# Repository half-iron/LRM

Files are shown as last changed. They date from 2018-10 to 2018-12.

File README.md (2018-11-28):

# LRM übersicht

### Ordner

- `axle_sensors` achsensoren info und firmware
- `NTiXL2` entält die python implementierung der serielle schnittstelle zur XL2 messgerät. Diesem Modul  
- `pyLRM` entält den python code notwendig für die scripts.

### Scripts

Die scripts dienen zur Bedienung der Messanlage. Die Scripts implementieren eine rehie von 
funktionen. Den Befehl `python3 scriptname.py -h` gibt Hinweise über die funktionalität und
 Anwendug der Scripts. 
 
Ein übersicht der implementierten funktionalitäten sind: 
- **xl2_device.py**: 
    - XL2 cycle power (strom aus und wieder ein)
    - XL2 test serial
    - XL2 mass <-> serial mode wechseln
    - XL2 mass mount und umount
    
- **messung.py** durchführt die Messung. Messdaten werden sowohl im XL2 wie im BBG generiert.

- **assign_tools.py**. Nach einer Messung müssen die XL2 und BBG Messdaten miteinander zugeordnet werden.

- **test_mail_logger.py** sendet einen testmail
    
- **test_axle_sensors.py** um axle sensor zu testen. ähnlich zur `messung.py` aber ohne XL2.

## Durchführung einer Messung
### Vorbereitungen

1. `pyLRM/config.py` file modifizieren falls nötig.

2. `pyLRM/passby.py` file modifizieren. Diesem File enthält die logik um die passby zu generieren. In zukunft diese änderung 
sollten in `pyLRM/config.py` durchgeführt werden durch subclassen von `passby.Passby` und neuschreiben der methode `run`

3. `pyLRM`, `NTiXL2`, Scripts und secret file auf BBG hochladen. 

### Messen

1. Stelle sicher dass den XL2 korrekt funktioniert und im serial modus ist. Benutze dafür 
den `xl2_device.py` script. z.B. mit:
    ```
    python3 xl2_device.py -test_serial
    ```
2. Starte die Messung mit  

    ```
       python3 messung.py TestMessung
    ```
    
    Den ordner `~\TestMessung` wird erstellt. Messdaten und logs sind dorthin gespeichert.
      
    Damit die messung auch nach den ssh logout weiterläuft muss den befehl in einen [screen](https://linuxize.com/post/how-to-use-linux-screen/) 
    Session  durchgeführt werden.
      
    ```bash
       screen
    ```
    Um den screen Session zu verlassen ctr-a d (detach).  
    Um den screen Session wieder zu öffnen `screen -r`
    Um den screen Session zu schliessen ctr-a k (kill).  

3. Stoppe die Messung  mit ctrl-c.
4. XL2 in mass modus bringen and mounten
    ```bash
        python3 xl2_device.py -to_mass -mount 
    ```
    
5. Daten runterladen
    - die XL2 daten befinden sich in `~\storagXL2`  
    - die messdaten (passby) befinden sich in `~\TestMessung`

6. XL2 wieder in serial modus bringen mit 
    ```bash
        python3 xl2_device.py -umount -eject
    ```

## Daten bereinigen und zuordnen

Zu diesem Zeitpunkt sind die passby daten und die XL2 daten in zwei ordner auf den PC. 

Als letzte Schritt nach einer Messung  müssen XL2 Daten und passby daten miteinander zugeordnet werden. 

Das Erfolgt nach diesem Schritten:

1. dauer von passby und XL2 aufnahmen prüfen 

2. zeit syncronisations zwischen passby und XL2 prüfen

3. XL2 aufnahmen und passby zuordnen

4. Neue ordnerstruktur herstellen 

Schritt 1 und 2 sind notwendig um Daten von oft auftretende Fehler zu Bereinigen. 
Diese Schritte werden mithilfe des `assign_tools.py` Script durchgeführt.

### Logs und passby daten analysieren 

Den notebook `visualize_axle_sensor_logs.ipynb` ist einen hilfmittel/Beispiel wie log Daten analysiert werden können.  
Den notebook `untersuche_assignement.ipynb` ist einen hilfmittel/Beispiel wie die Zuordnung untersucht werden kann.
  
## Ideen zur Verbesserungen

- Viele Probleme entstehen bei der Schnittstellen zum XL2 Gerät. Eine mögliche Verbesserung wäre
 die Messung nur einmal zu starten und entsprechend nur einmal stoppen. Damit wird nur ein XL2 filesatz generiert. Audiofiles werden aber dann gross
(XL2 gerät erstellt neue Files nach einer bestimmte grösse). Nur im postprocessing (assign) verden dann für die geloggte Vorbeifahrten (passby)  XL2 log und audiofiles ausgeschnitten.
**Wichtig**:
    - sync zeit Zwischen XL2 und passby(BBG) für jeden passby abfragen!
    - Messung trotzem jeden Tag neustarten damit log nicht zu gross werden un um fehler zu vermeiden.
    - Die Messung muss nicht den ganzen Tag laufen. In Zeiten ohne Verkehr (Nacht) sollte die Messung nicht laufen. 
        Zu dieser Zeiten XL2 ausschalten (mit relay), damit spart man Akku und den XL2 gerät wird resettet (Trägt zur stabilität der Messung zu). 
        Dazu können auch daten abgeholt werden. 
    - Aufpassen, kritische punkt im XL2 setum ist immer die Wahl des Messprofil.

- Alggemeine Programmierungs Verbesserungen:
    - NTiXL2 schnittstelle
    - passby module und passby class verbessern
    - Scripts verbessern. Vor allem das Argument parsing mit argparsing und die dazugehörige Dokumentation verbessern (wie im assign.py script)

- BBG: 
    - erstellen eines device tree overlay für den Relay.
    - Akku Spannung messen. Den PCB wäre dafür vorgesehn. Wobei dass problem ist dass den ADC nicht korrekt geschütz wurde. 
    Vielleicht eine bessere Lösung ist einen externen ADC (über I2C) zu wervenden. 
    Groove Module implementieren das schon und sind sehr einfach zu integrieren.  
    - Temperatur und feuchtigkeit messen. Wieder mit einen GrooveModul über I2C.

- Batterien für achszäler: Bohrmaschinen Batterien, eine genauere Messung des stromverbrauch ist zu machen.

- Mechanisches:
    - Dichtigkeit und betriebstemperaturen der Kisten prüfen 
    - Laser Lichtsensor alignement prüfen. Marke auf lichtsensor zeichen damit man sicher stellt dass den laser aligned ist.
    - Akkuverbindungsbox und Akkukabeln verbessern (Dichtigkehit und Srösse)
    -

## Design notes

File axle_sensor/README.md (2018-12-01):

## Grundlage
Ein Achssensor besteht grundsätzlich aus 3 bestandteile:
- Lichtschranke (LS). Die LS hat einen  Analoge output:
    - 10V => logical 1, wenn abgedekt (Rad steht im Sicht)
    - 0V => logical 0, wenn frei (freie Sicht)
- Mikrocontroller msp432 (MCU)
- XEee Radio Modul (XBee)

### Software idee 
Den Achzähler ist als State Maschine modelliert. 

**Zustände:**
1. IDLE: Setup und stromsparmodus. Die Transition  zu diesem Zustand erfolgt 
anhand einen Xbee pin Status.
2. AXLE_ON
3. AXLE_OFF
4. AXLE_ERR

**Intergrund 2kHz ISR, Low pass filter**   

    Der MCU tastet den LS Output, deren Wert `x_i` entweder 0 oder 1  ist, mit 2kHz ab. 
    Aus diesen Werte wird eine Summe aus die letzten  `sum_len` gelesen Werte gebildet `sum = Summe x_i`.
    Dazu wird in jeden Zustand ein counter `cnt` incrementiert mit 2kHZ takt.
     
**Transitions und actions**
- wenn `sum>(sum_len-threshold_ON)`: AXLE_OFF->AXLE_ON. Dann set `axle_off_time=cnt` dann set `cnt=0`
- wenn `sum<threshold_OFF`: AXLE_ON->AXLE_OFF. Dann  send msg AXLE mit`axle_off_time` und `axle_on_time=cnt` dann set `cnt=0`
- wenn `cnt>threshold_ERR`: AXLE_ON->AXLE_ERR. Dann  send msg AXLE_ERR mit`axle_off_time` 
- wenn `sum<threshold_OFF`: AXLE_ERR->AXLE_OFF. Dann set  `cnt=0`

Mehr Informationen im Code

### Einstellungen

Die State Maschine kann mit 4 parameter beeinflusst werden: `threshold_ERR,threshold_ON,threshold_OFF,sum_len`

##PrintedCircuitBoard (PCB)
Alle pcb sowohl für den axle_sensor wie für den BBG  wurden mirt KiCad hersetllt.

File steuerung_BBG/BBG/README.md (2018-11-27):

#Schritte um das BBG zu einrichten  

Stand 22.10.2018  

[Allgemeine BBG info](http://wiki.seeedstudio.com/BeagleBone_Green/)

1. sd karte vorbereiten  

    - BBG ist mit der image **image_name** *bone-debian-9.5-iot-armhf-2018-10-07-4gb* aufgerüstet.  [Download BBG image](https://beagleboard.org/latest-images).  
    Ich wervende immer iot image. 
    Teste sha256 checksum mit `sha256sum image_name.img.xz`.

    - Entpacke image:
    
        `xz -d image_name.img.xz > image_name.img`

    - Finde Sd-Karte name und brenne image auf Sd-Karte mit **karte_name**:
        ```bash
          sudo dd bs=4M if=image_name.img of=karte_name status=progress conv=fsync 
         ```
2. Allgemeines:  
    - Password wechseln
        ```bash
        passwd 
        ```
    - Update and upgrade
    - Grow sd card partition.  
    Die sd Karte hat nach dem brennen eine Partition grösse von ca 4GB. Um die Partition auf die 
    ganze sd-Karte grösse zu strecken diesem script durchführen.
         ```
          sudo /opt/scripts/tools/grow_partition.sh
         ```
        dann reboot. [Vertiefung](https://elinux.org/Beagleboard:Expanding_File_System_Partition_On_A_microSD)

3. Setup static ip.  
    Debian verwendet `connman`als network manager. Für weitere info sich an den manual wenden.
    Grundsätzlich funktioniert das einrichten des statische ip  wie folgt:  
    - Finde de service Name **ser_name** des ethernet network service.  
    
         ```
         sudo connmanctl services  
         
         ```  
         z.B: in meinem fall ist ser_name  **ethernet_84eb189c0c9e_cable**  
     
    - dann diesem Befehl eingeben
        ```
        connmanctl config ethernet_84eb189c0c9e_cable --ipv4 manual 192.168.5.5 255.255.255.0 192.168.5.1 --nameservers 8.8.8.8
        ```

4. ssh Tunnel einrichten. (im unterordner erklärt) 

9. Einrichten des UART für den Xbee. damit die UART Nummer 4 Schnittstelle aktiviert wird muss den korrekten device tree overlay geladen werden.  
Da erfolgt durch das modifizieren des uEnv.txt file an den Punkt `###Custom Cape`
    ```
    ###Custom Cape
    dtb_overlay=/lib/firmware/BB-UART4-00A0.dtbo
    ###
    ```
    Als Referenz benütze den abgelegte uEnv.txt File.

10. XL2 udev rules einrichten und fstab Zeile einfügen.  

    Den Abgelegte file `50-usb-XL2slm.rules` im `/etc/udev/rules.d/` copieren.
    Udev restarten mit `sudo udevadm control --reload-rules && udevadm trigger`.
      
    Zum fstab file `/etc/fstab` füge Zeile hinzu (prüfe UUID! mit `blkid`)   
    `UUID=9016-4EF8  /home/debian/storageXL2  vfat defaults,nofail,user,noauto  0  0`  
    
    Nach die udev Einstellungen sollte den XL2:  
     - wenn in serial modus, mit device name `/dev/XL2serial` erkennt werden. 
     - wenn in mass storage modus, sollte ein Disk auftauchen mit name `/dev/XL2storage` 
    
    Dank fstab das mounten sollte mit `mount storageXL2` erscheinen.   
    Umounten sollte mit `umount storageXL2` erscheinen. 
    Eject mit `eject /dev/XL2storage`

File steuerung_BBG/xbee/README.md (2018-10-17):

# LRMessanlage Xbee

In LRMesanlage kommuniziert die *steuerungBBG* und die *axle_sensor* mithilfe von [digi Xbee radio module](https://www.digi.com/xbee). Xbee Radiomodule sind an den *steuerungBBG* und die *axle_sensor* via serielle Schnittstelle (UART) verbunden. Mithilfe einen [UAR2USB Adapter](https://www.sparkfun.com/products/11812) lassen sich auch die Xbee module an PC verbinden.

- Den Xbee der *steuerungBBG* dient als *coordinator* und arbeitet in API mode.
- Die *axle_sensor* xbee sind *router* und arbeiten im *trasparent mode*.

## Xbee configurieren und testen

Am einfachsten werden xbee mithilfe des digi configurations program [XCTU](https://www.digi.com/products/xbee-rf-solutions/xctu-software/xctu) am PC configuriert und getestet. 
Das Erfolgt grundsätzlich in drei Schritte

1. Xbee auf UAR2USB einstecken und an PC verbinden
2. XCTU und xbee modul hinzufügen/finden 
3. xbee configurieren

Die [XCTU user guide](https://www.digi.com/resources/documentation/digidocs/90001458-13/) kann dafür hilfreich sein.

**Configurationsfile** für steuerungBBG (coordinator) und  axle_sensor sind in`LRMessanlage/steuerung_BBG/xbee` bzw. `LRMessanlage/axle_sensor/xbee` zu finden.

In diesem [link](https://alselectro.wordpress.com/2017/01/23/zigbee-xbee-s2c-how-to-configure-as-coordinator-router-end-device/) wird Schritt für Schritt den coordinator configuriert.

## Serielle Schnittstelle parameter

Die Configurationsfiles configurieren die Serielle Schnittstelle mit folgende parameter:

**steuerungBBG:**  57600/8/N/1/N - API 1; MAC: 0013A200414F9054

**axle_sensor:** 57600/8/N/1/N - AT; MAC: 0013A20041863136, 0013A200414F906D

## Xbee und python3

Digi hat einen python3 modul für die communication und setuop von xbee Modulen. [Documentation](https://xbplib.readthedocs.io/en/stable/)

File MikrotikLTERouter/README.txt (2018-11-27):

#Router setup

1. Mikrotik hat ein konfigurationsprogramm WinBox welches von https://mikrotik.com/download runtergeladen werden kann.
Als alternative man kann die KonfigurationsWeb interface werwenden.

2. MAC ADRESS der WLAN interface sind unten dem schwarzen deckel zu sehen.
 eth: B8:69:F4:08:BC:C3
 wlan: B8:69:F4:08:BC:C5

3. Router reset: reset knopf 5 sec gedrückt halten wärend boot bis LED flashen, dann loslassen.

4. Passwörter auf secret file

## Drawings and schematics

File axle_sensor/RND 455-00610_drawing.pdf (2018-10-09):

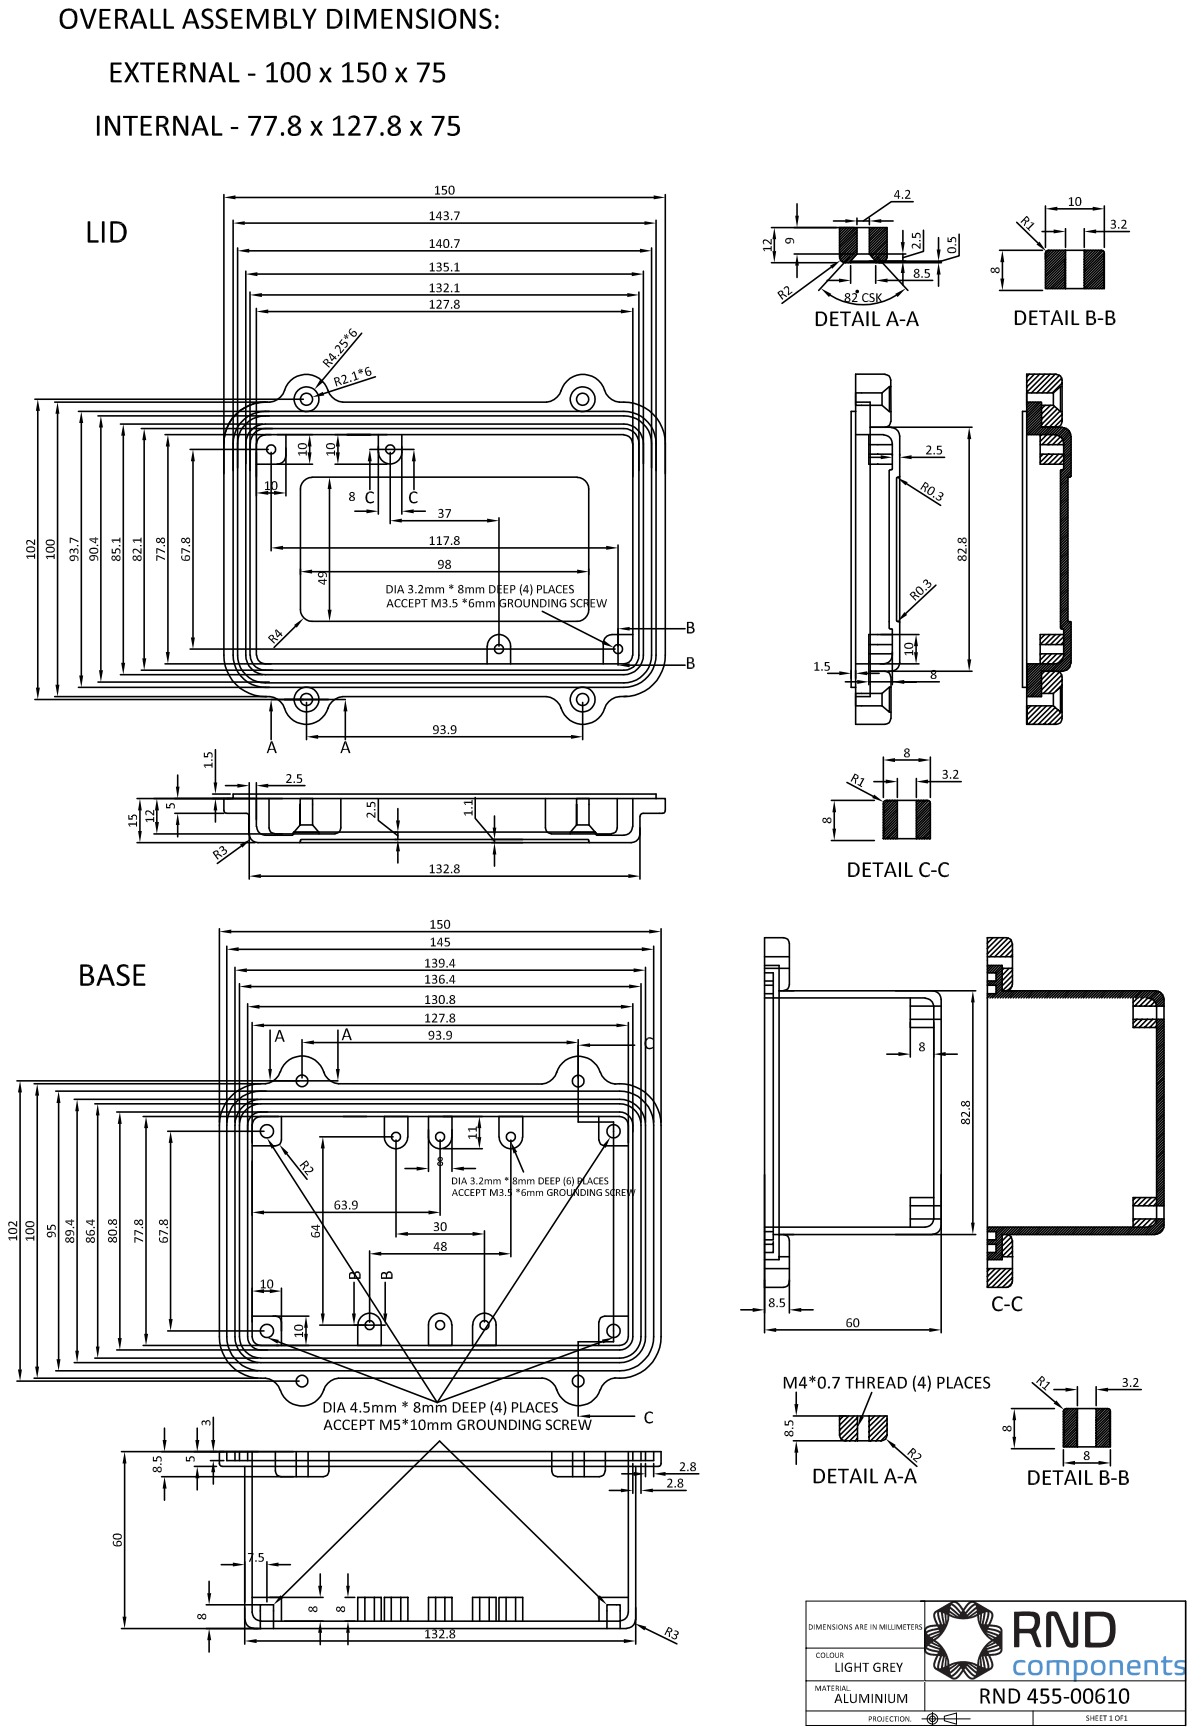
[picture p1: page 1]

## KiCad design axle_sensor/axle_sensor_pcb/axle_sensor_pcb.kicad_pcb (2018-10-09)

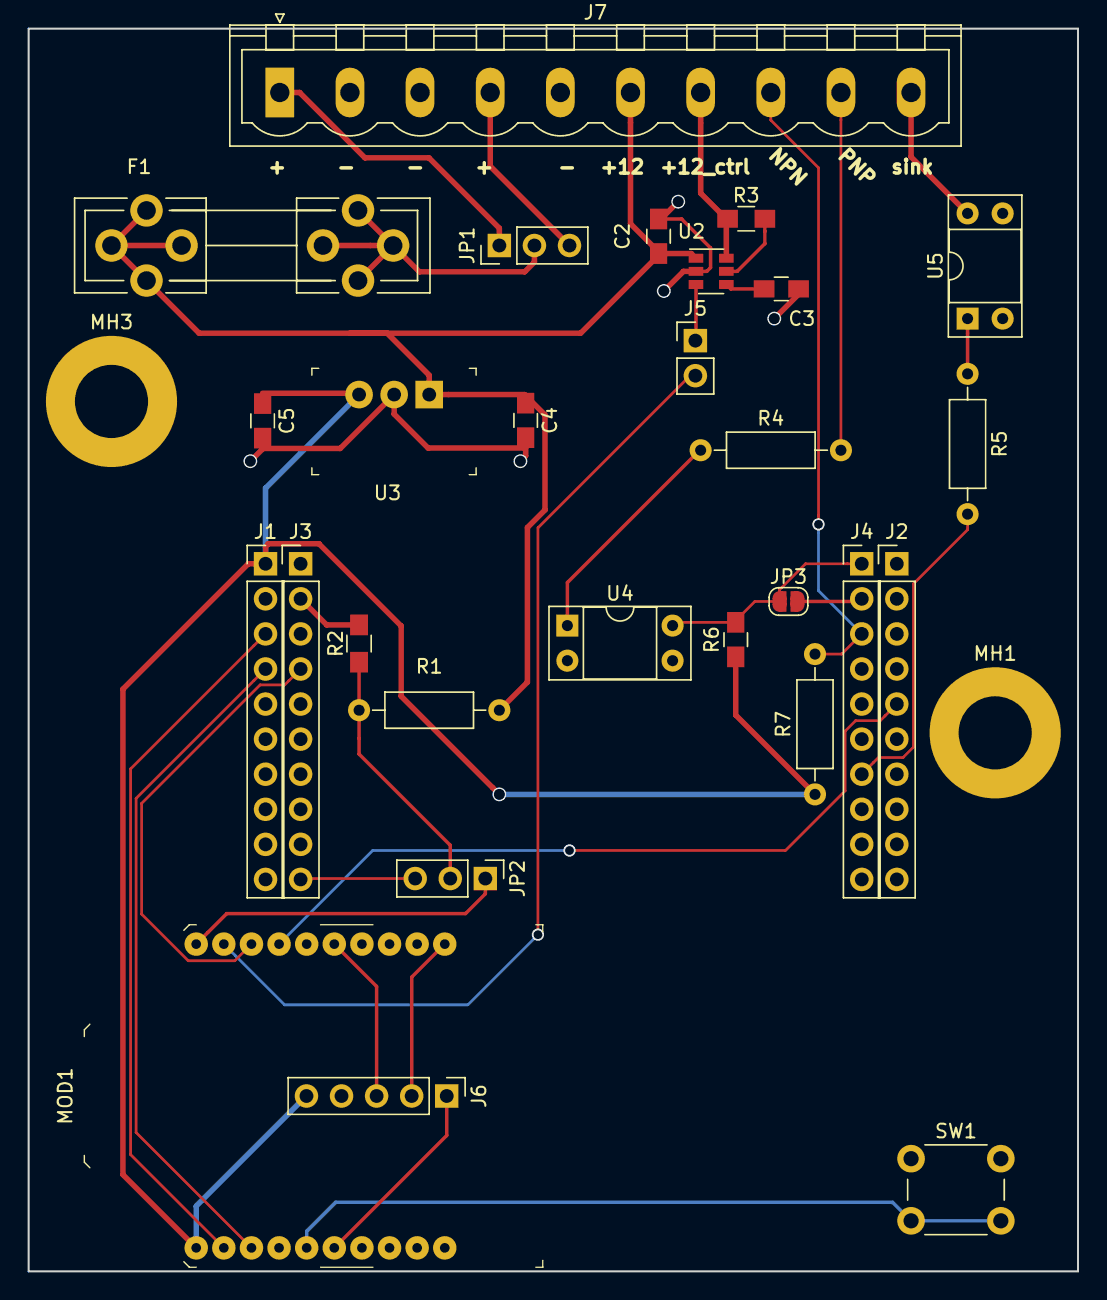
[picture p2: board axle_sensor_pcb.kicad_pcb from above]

Board: 2 copper layers, 76.0 x 90.0 mm, 30 parts (0 on the bottom side), 30 nets.

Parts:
C2: 1u; C_0805_HandSoldering
C3: 0.001u; C_0805_HandSoldering
C4: 10u; C_0805_HandSoldering
C5: 22u; C_0805_HandSoldering
F1: Fuse; Fuseholder5x20_horiz_open_universal_Type-III
J1: TI_BOOSTER_40_J1; PinHeader_1x10_P2.54mm_Vertical
J2: TI_BOOSTER_40_J2; PinHeader_1x10_P2.54mm_Vertical
J3: TI_BOOSTER_40_J3; PinHeader_1x10_P2.54mm_Vertical
J4: TI_BOOSTER_40_J4; PinHeader_1x10_P2.54mm_Vertical
J5: Conn_01x02; Pin_Header_Straight_1x02_Pitch2.54mm
J6: Conn_01x05; Pin_Header_Straight_1x05_Pitch2.54mm
J7: Screw_Terminal_01x10; PhoenixContact_MSTBVA-G_10x5.08mm_Vertical
JP1, JP2: Jumper_3_Open; Pin_Header_Straight_1x03_Pitch2.54mm
JP3: SolderJumper_2_Open; SolderJumper-2_P1.3mm_Open_RoundedPad1.0x1.5mm
MH1, MH3: MountingHole_Pad; MountingHole_5.3mm_M5_ISO7380_Pad
MOD1: XBP24-DMSIT-250_LTB; XBEE_PRO-20_THT
R1: 220k; R_Axial_DIN0207_L6.3mm_D2.5mm_P10.16mm_Horizontal
R2: 10k; R_0805_HandSoldering
R3: 1k; R_0805_HandSoldering
R4, R7: 1k; R_Axial_DIN0207_L6.3mm_D2.5mm_P10.16mm_Horizontal
R5: 220; R_Axial_DIN0207_L6.3mm_D2.5mm_P10.16mm_Horizontal
R6: 10k; C_0805_HandSoldering
SW1: SW_Push; SW_PUSH_6mm
U2: TPS22810DBVR; SOT-23-6
U3: V7805-500; 3-SIP_Module_V7805-500
U4, U5: TLP627; DIP-4_W7.62mm_Socket

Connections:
+12V: C2.2, C4.1, F1.1, J7.6, R1.1, U2.1, U3.1
/A0: J3.10, JP2.3
/NPN: J4.3, J7.8, R7.2
/P2.3: J4.7, R5.2
/P2.7: J4.1, JP3.1, R6.2, U4.4
/P4.0: J3.4, MOD1.18
/PNP: J7.9, R4.2
/RESET_MCU: J2.5, MOD1.17
/RX: J1.3, MOD1.2
/SENSOR_VCC: J7.7, R3.1, U2.6
/SHTDOWN_SENSOR: J5.2, MOD1.19
/TX: J1.4, MOD1.3
/sink: J7.10, U5.4
GND: C2.1, C3.2, C4.2, C5.2, J2.1, J3.2, J6.4, J7.2, J7.3, J7.5, MH1.1, MOD1.10, R2.2, SW1.1, U2.2, U3.2, U4.2, U4.3, U5.2, U5.3
unnamed: C3.1, U2.4
unnamed: F1.2, JP1.2
unnamed: J4.2, JP3.2
unnamed: J5.1, U2.3
unnamed: J6.1, MOD1.6
unnamed: J6.2, MOD1.11
unnamed: J6.3, MOD1.15
unnamed: J7.1, JP1.1
unnamed: J7.4, JP1.3
unnamed: JP2.1, MOD1.20
unnamed: JP2.2, R1.2, R2.1
unnamed: MOD1.5, SW1.2
unnamed: R3.2, U2.5
unnamed: R4.1, U4.1
unnamed: R5.1, U5.1
VCC: C5.1, J1.1, J6.5, MOD1.1, R6.1, R7.1, U3.3

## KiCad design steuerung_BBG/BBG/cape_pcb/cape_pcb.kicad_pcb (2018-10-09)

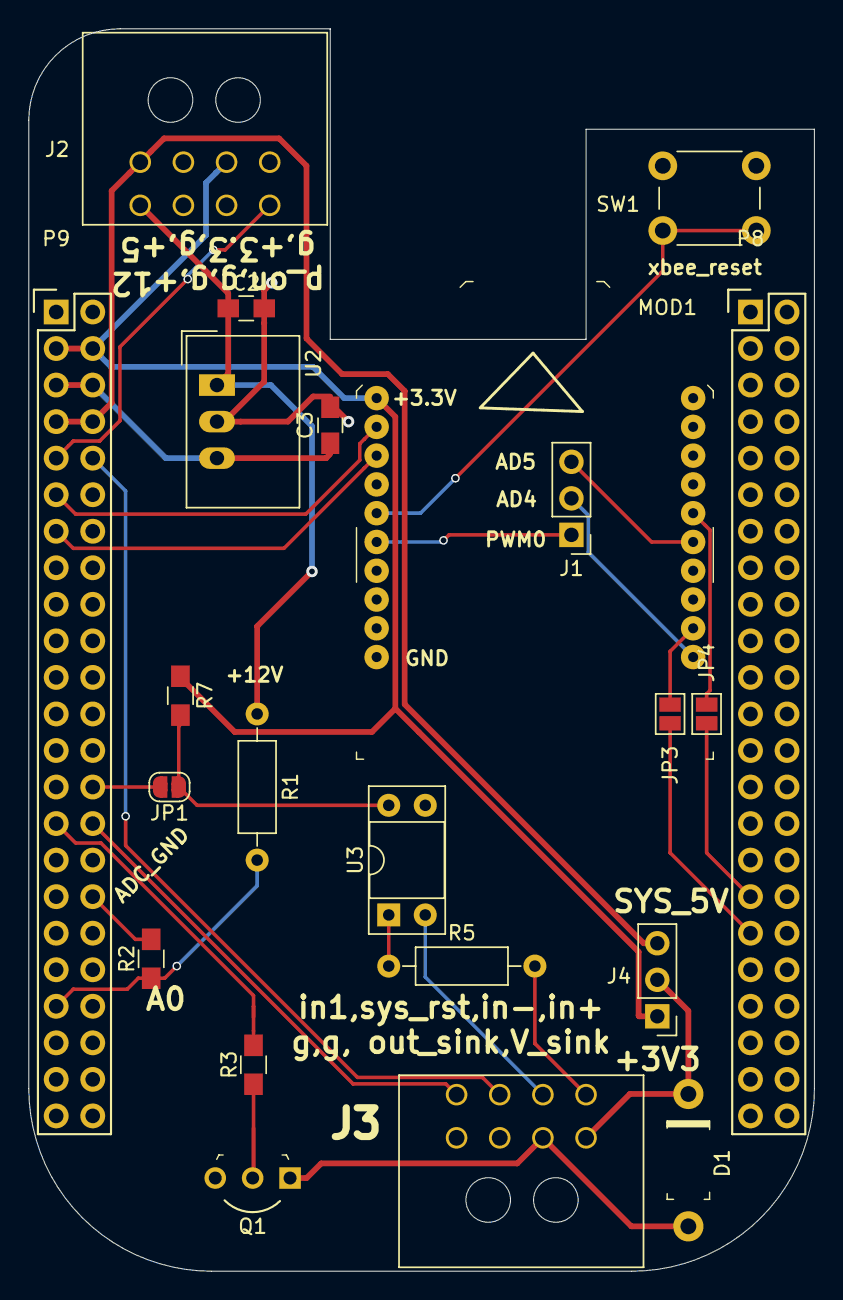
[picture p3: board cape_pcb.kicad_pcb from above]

Board: 2 copper layers, 54.6 x 86.4 mm, 22 parts (0 on the bottom side), 29 nets.

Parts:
C2, C3: 22u; C_0805_HandSoldering
D1: 1N4001-G; DO-41
J1, J4: Conn_01x03; Socket_Strip_Straight_1x03_Pitch2.54mm
J2, J3: Conn_01x08; Molex_Microfit3_Header_02x04_Angled_43045-080x
JP1: Jumper_2_Open; SolderJumper-2_P1.3mm_Open_RoundedPad1.0x1.5mm
JP3, JP4: Jumper_2_Open; SolderJumper-2_P1.3mm_Open_Pad1.0x1.5mm
MOD1: XBP24-DMSIT-250_LTB; XBEE_PRO-20_THT
P8, P9: BeagleBone_Black_Header; Socket_BeagleBone_Black
Q1: BC33740TA; TO-92-3_Formed_Leads
R1: 220k; R_Axial_DIN0207_L6.3mm_D2.5mm_P10.16mm_Horizontal
R2, R7: 10k; R_0805_HandSoldering
R3: 560; R_0805_HandSoldering
R5: 220; R_Axial_DIN0207_L6.3mm_D2.5mm_P10.16mm_Horizontal
SW1: SW_Push; SW_PUSH_6mm
U2: TSR_1-2450; DCDC-Conv_TRACO_TSR-1
U3: TLP627; DIP-4_W7.62mm_Socket

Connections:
+3V3: J2.3, J4.1, MOD1.1, P9.3, P9.4, R7.1
+5V: C3.1, P9.5, P9.6, U2.3
+12V: C2.1, J2.5, R1.1, U2.1
/in1+: J3.5, R5.2
/in1-: J3.6, U3.2
A0: P9.39, R1.2, R2.1
GNDA_ADC: P9.34, R2.2
GNDD: C2.2, C3.2, J2.2, J2.4, J2.6, J2.7, J3.3, J3.4, MOD1.10, P8.1, P8.2, P9.1, P9.2, P9.43, P9.44, P9.45, P9.46, Q1.3, SW1.1, U2.2, U3.3
IN0: JP1.2, P9.28
IN1: J3.8, P9.30
unnamed: D1.A, J3.2, Q1.1
unnamed: D1.K, J3.1, J4.2
unnamed: J1.1, MOD1.6
unnamed: J1.2, MOD1.11
unnamed: J1.3, MOD1.15
unnamed: JP1.1, R7.2, U3.4
unnamed: JP3.1, MOD1.12
unnamed: JP4.1, MOD1.16
unnamed: MOD1.5, SW1.2
unnamed: Q1.2, R3.1
unnamed: R5.1, U3.1
OUT0: P9.29, R3.2
PWR_BUT: J2.8, P9.9
SYS_5V: J2.1, J4.3, P9.7, P9.8
SYS_RESETN: J3.7, P9.10
UART4_CTS: JP3.2, P8.35
UART4_RTS: JP4.2, P8.33
UART4_RXD: MOD1.2, P9.11
UART4_TXD: MOD1.3, P9.13

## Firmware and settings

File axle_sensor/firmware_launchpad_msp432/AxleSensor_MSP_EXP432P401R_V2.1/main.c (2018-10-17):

/* DriverLib Includes */
#include <ti/devices/msp432p4xx/driverlib/driverlib.h>

/* Standard Includes */
#include <stdint.h>
#include <stdbool.h>

#define LED_RED GPIO_PIN0 //PORT2.0
#define LED_GREEN GPIO_PIN1//PORT2.1
#define LED_BLUE GPIO_PIN2//PORT2.2
#define LED_RED1 GPIO_PIN0//PORT1(1.0)
#define ERROR_LED LED_RED
#define AXLE_LED  LED_RED1

#define SYS_CLOCK 24000000//24MHZ
#define USER_TIMER_A_ISR_FREQ 2000 // Hz ISR TIMER_A frequency
#define TIMER_A_BASE_FREQ 32000 //Hz external oscillator(Q2)on Launchpad for ACLK 32 KHz
#define USER_TIMER_A_CCR (TIMER_A_BASE_FREQ/USER_TIMER_A_ISR_FREQ) //Hz external oscillator(Q2)on Launchpad for ACLK 32 KHz
#define WHEEL_COUNTER_SCALING 4 //wheel_off_counter and wheel_on_counter are scaled by this factor before sending

#define DEFAULT_THRESHOLD_ON 1
#define DEFAULT_SUM_LEN 4
#define DEFAULT_THRESHOLD_OFF 1
#define DEFAULT_THRESHOLD_ERR_S 2

//==========================================================================================
//MSG PROTOCOL
//============
//
//Messages longer than one byte (MSG from axle_sensor) are always
//stuffed using start ,stop and esc bytes
#define FRAME_START (0x7C)
#define FRAME_STOP (0x7D)
#define FRAME_ESC (0x7E)
//
//MSG from axle_sensor
//====================
//
//msg_out_axle:
//-------------
//send only in RDY state (green led on)
#define MSG_HEADER_AXLE (1)
#define MSG_HEADER_AXLE_ERROR (2)
//axle msg frame 6 byte length:
//MSG_HEADER_AXLE:uint_8t,      wheel_On_counter:uint_8t,  wheel_Off_counter:uint_32t
//
//axle error msg frame 4 byte length:
//MSG_HEADER_AXLE_ERROR:uint_8t,wheel_On_counter:uint_8t,   wheel_Off_counter:uint_32t
//
//msg_out_setup: setup response MSG
//---------------------------------
//send after a msg_in
//always 2 bytes long send only in IDLE state (green_led blinking)
//
//                                first byte                          second byte
#define MSG_HEADER_SETUP_OK (3)     // MSG_HEADER_SETUP_OK:uint_8t,     msg_in:uint_8t
#define MSG_HEADER_SETUP_ERROR (4)  // MSG_HEADER_SETUP_ERROR:uint_8t,  msg_in in:uint_8t
#define MSG_HEADER_T_ON (5)         // MSG_HEADER_T_ON:uint_8t,         threshold_ON :uint_8t
#define MSG_HEADER_T_OFF (6)        // MSG_HEADER_T_EFF:uint_8t,        threshold_OFF:uint_8t
#define MSG_HEADER_T_ERR (7)        // MSG_HEADER_T_ERR:uint_8t,        threshold_ERR:uint_8t
#define MSG_HEADER_SUM_LEN (8)      // MSG_HEADER_SUM_LEN:uint_8t,      sum_len:uint_8t
#define MSG_HEADER_ECHO (0xf1)      // MSG_HEADER_PING:uint_8t,     msg_in:uint_8t
//
//MSG to axle_sensor
//=================
//msg_in:
//-------
//Always only 1 byte long. Handle only in IDLE state (green_led blinking)
//

//Follow always response msg_out_setup
#define MSG_GET_SUM_LEN (1) //response MSG_HEADER_T_ON
#define MSG_GET_T_ON (2)    //response MSG_HEADER_T_ON
#define MSG_GET_T_OFF (3)   //response MSG_HEADER_T_OF
#define MSG_GET_T_ERR (4)   //response MSG_HEADER_T_ERR
//
//Follow always a response MSG_HEADER_SETUP_OK or MSG_HEADER_SETUP_ERROR
#define MSG_ECHO (0xf0)  //  >61
#define MSG_SET_SUM_LEN (10) // 11-20
#define MSG_SET_T_ON (20)   //  20-40
#define MSG_SET_T_OFF (40)  //  40-61
#define MSG_SET_T_ERR (60)  //  >61
//
//function prototypes and global  inherent MESG PROTOCOL
uint8_t MSG_axle(volatile uint8_t *msgdbuff, uint8_t wheel_on_counter,
                 uint32_t wheel_off_counter);
uint8_t MSG_axle_error(volatile uint8_t *msgdbuf, uint32_t wheel_off_counter);
void UART_trasmitFrame(volatile uint8_t *dataPointer, uint8_t nChar);
volatile uint8_t msg_out_dbuf[6];
uint8_t msg_in;
volatile uint8_t transmitNBytes;
// UART setup
const eUSCI_UART_Config uartConfig_A2 =\
//http://software-dl.ti.com/msp430/msp430_public_sw/mcu/msp430/MSP430BaudRateConverter/index.html
//http://www.samlewis.me/2015/05/using-msp432-eUSCI/
// SYSCLC   BAUD    BRDIV   UCxBRF  UCBRS
// 24       115200  13      0       37
// 24       9600    156     4       0
//  24      57600   26      0       111
        {
        EUSCI_A_UART_CLOCKSOURCE_SMCLK,          // SMCLK Clock Source
          26,          // BRDIV = 78 6
          0,          // UCxBRF = 2 8
          111,          // UCxBRS = 0 32
          EUSCI_A_UART_NO_PARITY,          // No Parity
          EUSCI_A_UART_LSB_FIRST,          // MSB First
          EUSCI_A_UART_ONE_STOP_BIT,          // One stop bit
          EUSCI_A_UART_MODE,          // UART mode
          EUSCI_A_UART_OVERSAMPLING_BAUDRATE_GENERATION         // Oversampling
        };

//end MSG PROTOCOL
//==========================================================================================

//================================================================
//STATE MASCINE
typedef enum _state_e
{
    STATE_IDLE_e = 0, STATE_RDY_e,
} state_e;

typedef enum _wheel_state_e
{
    WHEEL_OFF_e = 0, WHEEL_ON_e, WHEEL_ON_ERROR_e,
} wheel_state_e;

volatile state_e state;
volatile wheel_state_e wheelState;

volatile uint16_t threshold_ON, threshold_OFF, threshold_ERROR;
uint16_t threshold_ERROR_s, sum_len;
//end  STATE MASCHINE
//================================================================

//================================================================
// MOVING SUM
//
#define M_SUM_MAX_LEN 32       // Size of data arrays
typedef struct _MOVING_SUM_Obj_
{
    uint16_t sum_len;
    uint16_t sum;
    uint16_t index_0;       // points to field with oldest content
    volatile uint16_t *dbuffer_ptr;

} M_SUM_Obj;

void M_SUM_init(volatile M_SUM_Obj *moving_sum_obj,
                volatile uint16_t *dbuffer_ptr);
void M_SUM_setup(volatile M_SUM_Obj *moving_sum_obj, uint16_t sum_len);
void M_SUM_run(volatile M_SUM_Obj *moving_sum_obj, uint16_t x_new);
volatile M_SUM_Obj m_sum;
volatile uint16_t m_sum_dbuff[M_SUM_MAX_LEN];
//end  MOVING SUM
//================================================================
const Timer_A_UpModeConfig upModeConfig =\
 {
TIMER_A_CLOCKSOURCE_ACLK, // ACLK Clock Source
        TIMER_A_CLOCKSOURCE_DIVIDER_1, // ACLK/1 = 48MHz
        (USER_TIMER_A_CCR-1), // sR = 2048
        TIMER_A_TAIE_INTERRUPT_DISABLE, // Disable Timer ISR
        TIMER_A_CCIE_CCR0_INTERRUPT_ENABLE, // Disable CCR0
        TIMER_A_DO_CLEAR // Clear Counter
        };

uint32_t led_count, led_on_count;
int main(void)
{
    /* Halting the Watchdog */
    SystemInit();
    SystemCoreClockUpdate();

    MAP_WDT_A_holdTimer();

    /* Configuring LED as output*/
    MAP_GPIO_setAsOutputPin(GPIO_PORT_P1, LED_RED1);
    MAP_GPIO_setOutputLowOnPin(GPIO_PORT_P1, LED_RED1);
    MAP_GPIO_setAsOutputPin(GPIO_PORT_P2, LED_RED);
    MAP_GPIO_setOutputLowOnPin(GPIO_PORT_P2, LED_RED);
    MAP_GPIO_setAsOutputPin(GPIO_PORT_P2, LED_GREEN);
    MAP_GPIO_setOutputLowOnPin(GPIO_PORT_P2, LED_GREEN);
    MAP_GPIO_setAsOutputPin(GPIO_PORT_P2, LED_BLUE);
    MAP_GPIO_setOutputLowOnPin(GPIO_PORT_P2, LED_BLUE);

    //cell input GPIO
    /* Configuring P2.7 as an input  */
    MAP_GPIO_setAsInputPinWithPullUpResistor(GPIO_PORT_P2, GPIO_PIN7);

    //idle input GPIO
    /* Configuring P4.1 as an input  */
    MAP_GPIO_setAsInputPinWithPullDownResistor(GPIO_PORT_P4, GPIO_PIN0);

    /* Starting and enabling ACLK (32kHz) */
    MAP_CS_setReferenceOscillatorFrequency(CS_REFO_128KHZ);
    MAP_CS_initClockSignal(CS_ACLK, CS_REFOCLK_SELECT, CS_CLOCK_DIVIDER_4);

    /* Configuring TA0 UpMode */
    MAP_Timer_A_configureUpMode(TIMER_A0_BASE, &upModeConfig);
    MAP_Interrupt_enableInterrupt(INT_TA0_0);

    /* UART  P3.2 and P3.3 in UART A2*/
    MAP_GPIO_setAsPeripheralModuleFunctionInputPin(
            GPIO_PORT_P3, GPIO_PIN2 | GPIO_PIN3, GPIO_PRIMARY_MODULE_FUNCTION);
    CS_setDCOCenteredFrequency(CS_DCO_FREQUENCY_24);
    MAP_UART_initModule(EUSCI_A2_BASE, &uartConfig_A2);
    MAP_UART_enableModule(EUSCI_A2_BASE);

    /* Enabling SRAM Bank Retention */
    MAP_SysCtl_enableSRAMBankRetention(SYSCTL_SRAM_BANK1);

    /* Enabling MASTER interrupts */
    MAP_Interrupt_enableMaster();

    //state = STATE_IDLE_e;
    wheelState = WHEEL_OFF_e;
    state = STATE_IDLE_e;
    threshold_ERROR_s = DEFAULT_THRESHOLD_ERR_S;
    threshold_ERROR = threshold_ERROR_s * USER_TIMER_A_ISR_FREQ;
    threshold_OFF = DEFAULT_THRESHOLD_OFF;
    threshold_ON = DEFAULT_THRESHOLD_ON;
    sum_len = DEFAULT_SUM_LEN;
    transmitNBytes = 0;
    led_count = 0;

    M_SUM_init(&m_sum, m_sum_dbuff);

    while (1)
    {
        //
        if (state == STATE_IDLE_e)
        {
            if (led_count > 0xA000)
            {
                led_count = 0;
                MAP_GPIO_toggleOutputOnPin(GPIO_PORT_P2, LED_GREEN);
            }
            else
            {
                led_count++;
            }
            //handle incoming frame
            if (MAP_UART_getInterruptStatus(EUSCI_A2_BASE,
            EUSCI_A_UART_RECEIVE_INTERRUPT_FLAG))
            {
                msg_in = MAP_UART_receiveData(EUSCI_A2_BASE);
                //

                if (msg_in >= MSG_ECHO)
                {
                    msg_out_dbuf[0] = MSG_HEADER_ECHO;
                    msg_out_dbuf[1] = msg_in;

                }

                else if (msg_in > MSG_SET_T_ERR)
                {
                    if ((msg_in - MSG_SET_T_ERR) < 5)
                    {
                        threshold_ERROR_s = msg_in - MSG_SET_T_ERR;
                        threshold_ERROR =
                                threshold_ERROR_s * USER_TIMER_A_ISR_FREQ;
                        msg_out_dbuf[0] = MSG_HEADER_SETUP_OK;
                        msg_out_dbuf[1] = msg_in;
                    }
                    else
                    {
                        msg_out_dbuf[0] = MSG_HEADER_SETUP_ERROR;
                        msg_out_dbuf[1] = msg_in;
                    }
                }
                else if (msg_in >= MSG_SET_T_OFF)
                {
                    if ((msg_in - MSG_SET_T_OFF) < (sum_len) / 2)
                    {
                        threshold_OFF = msg_in - MSG_SET_T_OFF;
                        msg_out_dbuf[0] = MSG_HEADER_SETUP_OK;
                        msg_out_dbuf[1] = msg_in;
                    }
                    else
                    {
                        msg_out_dbuf[0] = MSG_HEADER_SETUP_ERROR;
                        msg_out_dbuf[1] = msg_in;
                    }
                }
                else if (msg_in >= MSG_SET_T_ON)
                {
                    if ((msg_in - MSG_SET_T_ON) < (sum_len) / 2)
                    {
                        threshold_ON = msg_in - MSG_SET_T_ON;
                        msg_out_dbuf[0] = MSG_HEADER_SETUP_OK;
                        msg_out_dbuf[1] = msg_in;
                    }
                    else
                    {
                        msg_out_dbuf[0] = MSG_HEADER_SETUP_ERROR;
                        msg_out_dbuf[1] = msg_in;
                    }
                }
                else if (msg_in > MSG_SET_SUM_LEN)
                {
                    if ((msg_in - MSG_SET_SUM_LEN) <= 5)
                    {
                        sum_len = 1 << (msg_in - MSG_SET_SUM_LEN); //sum len =2**x, x in [1:5], max 32
                        msg_out_dbuf[0] = MSG_HEADER_SETUP_OK;
                        msg_out_dbuf[1] = msg_in;
                    }
                    else
                    {
                        msg_out_dbuf[0] = MSG_HEADER_SETUP_ERROR;
                        msg_out_dbuf[1] = msg_in;
                    }
                }
                else if (msg_in == MSG_GET_SUM_LEN)
                {
                    msg_out_dbuf[0] = MSG_HEADER_SUM_LEN;
                    msg_out_dbuf[1] = (uint8_t) sum_len;
                }
                else if (msg_in == MSG_GET_T_ON)
                {
                    msg_out_dbuf[0] = MSG_HEADER_T_ON;
                    msg_out_dbuf[1] = (uint8_t) threshold_ON;
                }
                else if (msg_in == MSG_GET_T_OFF)
                {
                    msg_out_dbuf[0] = MSG_HEADER_T_OFF;
                    msg_out_dbuf[1] = (uint8_t) threshold_OFF;
                }
                else if (msg_in == MSG_GET_T_ERR)
                {
                    msg_out_dbuf[0] = MSG_HEADER_T_ERR;
                    msg_out_dbuf[1] = (uint8_t) threshold_ERROR_s;
                }
                else
                {
                    msg_out_dbuf[0] = MSG_HEADER_SETUP_ERROR;
                    msg_out_dbuf[1] = msg_in;
                }
                UART_trasmitFrame((uint8_t *) (msg_out_dbuf), 2);
            }

            //transition
            if (MAP_GPIO_getInputPinValue(GPIO_PORT_P4, GPIO_PIN0))   //pin high
            {
                M_SUM_setup(&m_sum, sum_len);
                state = STATE_RDY_e;
                MAP_Timer_A_clearTimer(TIMER_A0_BASE);
                MAP_Timer_A_startCounter(TIMER_A0_BASE, TIMER_A_UP_MODE);
                MAP_GPIO_setOutputHighOnPin(GPIO_PORT_P2, LED_GREEN);
            }

        }
        else if (state == STATE_RDY_e)
        {
            //send axle data if necessary
            if (transmitNBytes > 0)
            {
                UART_trasmitFrame((uint8_t *) (msg_out_dbuf), transmitNBytes);
                transmitNBytes = 0;
            }
            //change state if sleep rdy
            if ( MAP_GPIO_getInputPinValue(GPIO_PORT_P4, GPIO_PIN0) == 0)
            {
                MAP_Timer_A_stopTimer(TIMER_A0_BASE);
                transmitNBytes = 0;
                state = STATE_IDLE_e;
            } //pin high
        }
//transmit message if necessary

    }
}

//******************************************************************************
//
//This is the TIMERA interrupt vector service routine.
//
//******************************************************************************
// messages are send at the end of wheel on or at the begininnig of wheel_err

void TA0_0_IRQHandler(void)
{
    static uint32_t wheel_on_count;
    static uint32_t wheel_off_count;
    MAP_GPIO_setOutputHighOnPin(GPIO_PORT_P2, LED_BLUE);
    MAP_Timer_A_clearCaptureCompareInterrupt(TIMER_A0_BASE,
    TIMER_A_CAPTURECOMPARE_REGISTER_0); //moving average
    M_SUM_run(&m_sum, 1 - MAP_GPIO_getInputPinValue(GPIO_PORT_P2, GPIO_PIN7));

    if (wheelState == WHEEL_OFF_e)
    {
        wheel_off_count++;
        if (m_sum.sum > (m_sum.sum_len - threshold_ON))
        {
            wheelState = WHEEL_ON_e;
            MAP_GPIO_setOutputHighOnPin(GPIO_PORT_P1, AXLE_LED);
            wheel_on_count = 0;
        }

    }
    else if (wheelState == WHEEL_ON_e)
    {
        wheel_on_count++;
        if (m_sum.sum < threshold_OFF)
        {
            wheelState = WHEEL_OFF_e;
            MAP_GPIO_setOutputLowOnPin(GPIO_PORT_P1, AXLE_LED);
            //send message time wheel on  and time inbetween
            transmitNBytes = MSG_axle(msg_out_dbuf,
                                      (uint8_t) (wheel_on_count/WHEEL_COUNTER_SCALING),
                                      (wheel_off_count/WHEEL_COUNTER_SCALING )); //time in ms
            wheel_off_count = 0;

        }
        else if (wheel_on_count > threshold_ERROR)
        {
            wheelState = WHEEL_ON_ERROR_e;
            MAP_GPIO_setOutputHighOnPin(GPIO_PORT_P2, ERROR_LED);
            transmitNBytes = MSG_axle_error(msg_out_dbuf,
                                            (wheel_off_count / WHEEL_COUNTER_SCALING)); //time in ms
            wheel_off_count = 0;
        }

    }
    else if (wheelState == WHEEL_ON_ERROR_e)
    {   //
        wheel_on_count++;
        if (m_sum.sum == 0)
        {
            MAP_GPIO_setOutputLowOnPin(GPIO_PORT_P1, AXLE_LED);
            MAP_GPIO_setOutputLowOnPin(GPIO_PORT_P2, ERROR_LED);
            wheelState = WHEEL_OFF_e;

        }
    }
    MAP_GPIO_setOutputLowOnPin(GPIO_PORT_P2, LED_BLUE);

}

void M_SUM_init(volatile M_SUM_Obj *moving_sum_obj,
                volatile uint16_t *dbuffer_ptr)
{
    moving_sum_obj->dbuffer_ptr = dbuffer_ptr;
}
void M_SUM_setup(volatile M_SUM_Obj *moving_sum_obj, uint16_t sum_len)
{
    uint16_t i;
    moving_sum_obj->index_0 = 0;
    moving_sum_obj->sum_len = sum_len;
    moving_sum_obj->sum = 0;
    for (i = 0; i < M_SUM_MAX_LEN; ++i)
    {
        moving_sum_obj->dbuffer_ptr[i] = 0;
    }
}

void M_SUM_run(volatile M_SUM_Obj *moving_sum_obj, uint16_t x_new)
{
    uint16_t x_oldest;
    if ((++moving_sum_obj->index_0) == moving_sum_obj->sum_len)
    {
        moving_sum_obj->index_0 = 0;
    }
    //retrive x_old from data buffer
    x_oldest = moving_sum_obj->dbuffer_ptr[moving_sum_obj->index_0];
    //calculate the moving average of <x>=sum(x_i)/N by adding (x_old/N - x_old/N)
    moving_sum_obj->sum += x_new - x_oldest;
    moving_sum_obj->dbuffer_ptr[moving_sum_obj->index_0] = x_new;
}

uint8_t MSG_axle(volatile uint8_t *msgdbuff, uint8_t wheel_on_counter,
                 uint32_t wheel_off_counter)
{
    volatile uint8_t *p;
    p = msgdbuff;
    *(p) = MSG_HEADER_AXLE;
    *(p + 1) = wheel_on_counter;
    *(p + 2)= (uint8_t)(wheel_off_counter);
    *(p + 3)= (uint8_t)(wheel_off_counter>>8);
    *(p + 4)= (uint8_t)(wheel_off_counter>>16);
    *(p + 5)= (uint8_t)(wheel_off_counter>>24);
    return 6;
}

uint8_t MSG_axle_error(volatile uint8_t *msgdbuf, uint32_t wheel_off_counter)
{
    volatile uint8_t *p;
    p = msgdbuf;
    *(p) = MSG_HEADER_AXLE_ERROR;
    *(p + 1)= (uint8_t)(wheel_off_counter);
    *(p + 2)= (uint8_t)(wheel_off_counter>>8);
    *(p + 3)= (uint8_t)(wheel_off_counter>>16);
    *(p + 4)= (uint8_t)(wheel_off_counter>>24);
    return 5;
}

void UART_trasmitFrame(volatile uint8_t *dataPointer, uint8_t nChar)
{
    uint8_t b;
    uint8_t i;
    //Transmit START
    while (!MAP_UART_getInterruptStatus(EUSCI_A2_BASE,
    EUSCI_A_UART_TRANSMIT_INTERRUPT_FLAG))
        ;
    MAP_UART_transmitData(EUSCI_A2_BASE, FRAME_START);
    //transmit Data
    for (i = 0; i < nChar; i++)
    {
        b = *(dataPointer + i);
        if ((b == FRAME_ESC) | (b == FRAME_START) | (b == FRAME_STOP))
        {
            while (!MAP_UART_getInterruptStatus(
                    EUSCI_A2_BASE,
                    EUSCI_A_UART_TRANSMIT_INTERRUPT_FLAG))
                ;
            MAP_UART_transmitData(EUSCI_A2_BASE, FRAME_ESC);
        }
        while (!MAP_UART_getInterruptStatus(
                EUSCI_A2_BASE,
                EUSCI_A_UART_TRANSMIT_INTERRUPT_FLAG))
            ;
        MAP_UART_transmitData(EUSCI_A2_BASE, b);
    }
    //Transmit STOP
    while (!MAP_UART_getInterruptStatus(EUSCI_A2_BASE,
    EUSCI_A_UART_TRANSMIT_INTERRUPT_FLAG))
        ;
    MAP_UART_transmitData(EUSCI_A2_BASE, FRAME_STOP);
}

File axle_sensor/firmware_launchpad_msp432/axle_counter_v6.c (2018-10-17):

/* --COPYRIGHT--,BSD
 * Copyright (c) 2017, Texas Instruments Incorporated
 * All rights reserved.
 *
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
 * *  Redistributions of source code must retain the above copyright
 *    notice, this list of conditions and the following disclaimer.
 *
 * *  Redistributions in binary form must reproduce the above copyright
 *    notice, this list of conditions and the following disclaimer in the
 *    documentation and/or other materials provided with the distribution.
 *
 * *  Neither the name of Texas Instruments Incorporated nor the names of
 *    its contributors may be used to endorse or promote products derived
 *    from this software without specific prior written permission.
 *
 * THIS SOFTWARE IS PROVIDED BY THE COPYRIGHT HOLDERS AND CONTRIBUTORS "AS IS"
 * AND ANY EXPRESS OR IMPLIED WARRANTIES, INCLUDING, BUT NOT LIMITED TO,
 * THE IMPLIED WARRANTIES OF MERCHANTABILITY AND FITNESS FOR A PARTICULAR
 * PURPOSE ARE DISCLAIMED. IN NO EVENT SHALL THE COPYRIGHT OWNER OR
 * CONTRIBUTORS BE LIABLE FOR ANY DIRECT, INDIRECT, INCIDENTAL, SPECIAL,
 * EXEMPLARY, OR CONSEQUENTIAL DAMAGES (INCLUDING, BUT NOT LIMITED TO,
 * PROCUREMENT OF SUBSTITUTE GOODS OR SERVICES; LOSS OF USE, DATA, OR PROFITS;
 * OR BUSINESS INTERRUPTION) HOWEVER CAUSED AND ON ANY THEORY OF LIABILITY,
 * WHETHER IN CONTRACT, STRICT LIABILITY, OR TORT (INCLUDING NEGLIGENCE OR
 * OTHERWISE) ARISING IN ANY WAY OUT OF THE USE OF THIS SOFTWARE,
 * EVEN IF ADVISED OF THE POSSIBILITY OF SUCH DAMAGE.
 * --/COPYRIGHT--*/
/* DriverLib Includes */
#include <ti/devices/msp432p4xx/driverlib/driverlib.h>

/* Standard Includes */
#include <stdint.h>
#include <stdbool.h>

#define LED_RED GPIO_PIN0 //PORT2
#define LED_GREEN GPIO_PIN1//PORT2
#define LED_BLUE GPIO_PIN2//PORT2
#define LED_RED1 GPIO_PIN0//PORT1(1.0)
#define ERROR_LED LED_RED
#define AXLE_LED  LED_RED1

//transmit nCHAR bytes starting at dataPointer. LSB first

//ZEITEN einstellungen ms
#define DELAY_HIGHtoLOW 10
#define DELAY_LOWtoHIGH 10
#define DELAY_MAX_LOW 1000
#define DELAY_STOP 3000

#define SYS_CLOCK 24000000//24MHZ

#define TICK_PER_mSECONDS (SYS_CLOCK/(16*1000)) // ACLK and TIMER 4 prescaler

#define TICK_DELAY_HIGHtoLOW  ((int)TICK_PER_mSECONDS*DELAY_HIGHtoLOW)
#define TICK_DELAY_LOWtoHIGH ((int)TICK_PER_mSECONDS*DELAY_LOWtoHIGH)
#define TICK_DELAY_MAX_LOW ((int)TICK_PER_mSECONDS*DELAY_MAX_LOW)
#define TICK_DELAY_STOP ((int)TICK_PER_mSECONDS*DELAY_STOP)
//===========
//MSG PROTOCOL
//============
//ADDRESS 1st Byte
#define DEVICE_ADDRESS  1
#define MASTER_ADDRESS  0
#define MSG_ADDRESS_TO 0x0F
#define MSG_ADDRESS_FROM 0xF0

#define MSG_TO_MASTER  (((DEVICE_ADDRESS<<4)& MSG_ADDRESS_FROM) | (MASTER_ADDRESS& MSG_ADDRESS_TO))

//HEADERS 2nd Byte

//DATA HEADERS (no RESPONSE)
#define MSG_HEADER_START (1)
#define MSG_HEADER_STOP (2)
#define MSG_HEADER_AXLE (3)

//COMMAND RESPONSe HEADER
#define MSG_HEADER_COMMAND (16)
#define MSG_HEADER_RESPONSE (17)

//DEBUG HEADER
#define MSG_HEADER_WARNING (18)
#define MSG_HEADER_ERROR (18)

#define API 1
#define TRANSPARENT 2
#define MESSAGING_PROTOCOL TRANSPARENT

/***********************************************************************
 * DATA MSG
 * =======
 *
 * -START: passbyCounter:uint_16t
 * -AXLE:  passbyCounter:uint_16t,axleCounter:uint_16t,axleTime:uint_16t
 * -STOP:  passbycounter:uint_16t,axleCounter:uint_16t,stopTime:uint_16t
 *
 * -TICKFREQ: tickfrequency:uint_16t
 *
 *
 *
 * COMMAND RESPONSE MSG:
 * ====================
 *
 * -COMMAND: command:uint8_t, command_id:uint8_t, command_data: DATA_MSG
 * -RESPONSE: command:uint8_t, command_id:uint8_t, response_data: DATA_MSG
 *
 * COMMANDTYPES
 * ------------
 *
 * - RESET: NO DATARESPONSE
 * - GET_TICK_FREQ: TICKFREQ
 *
 * DEBUG MSG:
 *
 * -ERROR:errortype:uint8_t
 *
 *
 *****************************************************************************
 */

uint8_t MSG_START(uint8_t *msg, uint16_t passbyCounter)
{
    uint8_t *p;
    p = msg;
    *p = MSG_TO_MASTER;
    *(p + 1) = MSG_HEADER_START;
    memcpy((p + 2), &passbyCounter, 2);
    return 4;
}

uint8_t MSG_AXLE(uint8_t *msg, uint16_t passbyCounter, uint16_t axleCounter,
                 uint16_t axleTime)
{
    uint8_t *p;
    p = msg;
    *p = MSG_TO_MASTER;
    *(p + 1) = MSG_HEADER_AXLE;
    memcpy((p + 2), &passbyCounter, 2);
    memcpy((p + 4), &axleCounter, 2);
    memcpy((p + 6), &axleTime, 2);
    return 8;
}
uint8_t MSG_STOP(uint8_t *msg, uint16_t passbyCounter, uint16_t axleCounter,
                 uint16_t stopTime)
{
    uint8_t *p;
    p = msg;
    *p = MSG_TO_MASTER;
    *(p + 1) = MSG_HEADER_STOP;
    memcpy((p + 2), &passbyCounter, 2);
    memcpy((p + 4), &axleCounter, 2);
    memcpy((p + 6), &stopTime, 2);
    return 8;
}

uint8_t MSG_ERROR(uint8_t *msg)
{
    uint8_t *p;
    p = msg;
    *p = MSG_TO_MASTER;
    *(p + 1) = MSG_HEADER_ERROR;
    return 2;
}

//FRAME bytes
#define FRAME_START (0x7C) // char "\r\r\r\n"
#define FRAME_STOP (0x7D)
#define FRAME_ESC (0x7E)
const eUSCI_UART_Config uartConfig_A2 =
//UART clocking
//http://software-dl.ti.com/msp430/msp430_public_sw/mcu/msp430/MSP430BaudRateConverter/index.html
//http://www.samlewis.me/2015/05/using-msp432-eUSCI/
// SYSCLC   BAUD    BRDIV   UCxBRF  UCBRS
// 24       115200  13      0       37
// 24       9600    156     4       0
//  24      57600   26      0       111
// 12       9600    78      2       0
// 12       115200  6       8       32
        {
        EUSCI_A_UART_CLOCKSOURCE_SMCLK,          // SMCLK Clock Source
          26,                                      // BRDIV = 78 6
          0,                                       // UCxBRF = 2 8
          111,                                      // UCxBRS = 0 32
          EUSCI_A_UART_NO_PARITY,                  // No Parity
          EUSCI_A_UART_LSB_FIRST,                  // MSB First
          EUSCI_A_UART_ONE_STOP_BIT,               // One stop bit
          EUSCI_A_UART_MODE,                       // UART mode
          EUSCI_A_UART_OVERSAMPLING_BAUDRATE_GENERATION  // Oversampling
        };

//transmit nCHAR bytes starting at dataPointer. LSB first
#if MESSAGING_PROTOCOL == API
void UART_trasmitFrame(uint8_t *dataPointer, uint8_t nChar)
{
    uint8_t b;
    uint8_t i;
    //transmit Data
    for (i = 0; i < nChar; i++)
    {
        b = *(dataPointer + i);
        while (!MAP_UART_getInterruptStatus(
                        EUSCI_A0_BASE, EUSCI_A_UART_TRANSMIT_INTERRUPT_FLAG))
        ;
        MAP_UART_transmitData(EUSCI_A2_BASE, b);
    }

}
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

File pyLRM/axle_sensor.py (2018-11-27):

import time
from digi.xbee.devices import TimeoutException, IOMode
from digi.xbee.io import IOLine,IOValue
import struct
import math
# ==========================================================================================
# MSG PROTOCOL
# ============
#
# Messages longer than one byte (MSG from axle_sensor) are always
# stuffed using start ,stop and esc bytes
FRAME_START= (0x7C)
FRAME_STOP =(0x7D)
FRAME_ESC =(0x7E)
#
# MSG from axle_sensor
# ====================
#
# msg_out_axle:
# -------------
# send only in RDY state (green led on)
MSG_HEADER_AXLE=(1)
MSG_HEADER_AXLE_ERROR=(2)
# axle msg frame 6 byte length:
# MSG_HEADER_AXLE:uint_8t,      wheel_On_counter:uint_8t,  wheel_Off_counter:uint_32t
#
# axle error msg frame 4 byte length:
# MSG_HEADER_AXLE_ERROR:uint_8t,wheel_On_counter:uint_8t,   wheel_Off_counter:uint_32t
#
# msg_out_setup: setup response MSG
# ---------------------------------
# send after a msg_in
# always 2 bytes long send only in IDLE state (green_led blinking)
#
#                                 first byte                          second byte
MSG_HEADER_SETUP_OK=(3)     #  MSG_HEADER_SETUP_OK:uint_8t,     msg_in:uint_8t
MSG_HEADER_SETUP_ERROR=(4)  #  MSG_HEADER_SETUP_ERROR:uint_8t,  msg_in in:uint_8t
MSG_HEADER_T_ON=(5)         #  MSG_HEADER_T_ON:uint_8t,         threshold_ON :uint_8t
MSG_HEADER_T_OFF=(6)        #  MSG_HEADER_T_EFF:uint_8t,        threshold_OFF:uint_8t
MSG_HEADER_T_ERR=(7)        #  MSG_HEADER_T_ERR:uint_8t,        threshold_ERR:uint_8t
MSG_HEADER_SUM_LEN=(8)      #  MSG_HEADER_SUM_LEN:uint_8t,      sum_len:uint_8t
MSG_HEADER_ECHO=(0xf1)      #  MSG_HEADER_PING:uint_8t,         msg_in:uint_8t
#
# MSG to axle_sensor
# =================
# msg_in:
# -------
# Always only 1 byte long. Handle only in IDLE state (green_led blinking)
#
# Follow always response msg_out_setup
MSG_GET_SUM_LEN=(1) # response MSG_HEADER_T_ON
MSG_GET_T_ON=(2)    # response MSG_HEADER_T_ON
MSG_GET_T_OFF=(3)   # response MSG_HEADER_T_OF
MSG_GET_T_ERR=(4)   # response MSG_HEADER_T_ERR
#
# Follow always a response MSG_HEADER_SETUP_OK or MSG_HEADER_SETUP_ERROR
MSG_ECHO=(0xf0)  #
MSG_SET_SUM_LEN=(10) #  11-20
MSG_SET_T_ON=(20)   #   20-40
MSG_SET_T_OFF=(40)  #   40-61
MSG_SET_T_ERR=(60)  #   >61


class AxleSensorException(Exception):
    pass


def frame_stuffing(unstuffed):
    # https:# eli.thegreenplace.net/2009/08/12/framing-in-serial-communications/
    stuffed = bytearray()
    stuffed.append(FRAME_START)
    # escape
    for i in unstuffed:
        if i in [FRAME_START, FRAME_STOP, FRAME_ESC]:
            stuffed.append(FRAME_ESC)
            stuffed.append(i)
        else:
            stuffed.append(i)
    stuffed.append(FRAME_STOP)
    return stuffed

def unstuff_frame_from_serial_data():
    # https:# eli.thegreenplace.net/2009/08/12/framing-in-serial-communications/
    unstuffed_frames=[]
    _partial_frame=None
    esc=None
    while True:
        new_bytes = yield unstuffed_frames
        unstuffed_frames=[]
        for b in bytearray(new_bytes):
            if esc:
                esc = False
                if isinstance(_partial_frame, bytearray):
                    _partial_frame.append(b)
            elif b == FRAME_ESC:
                esc = True
            elif b == FRAME_START:
                _partial_frame = bytearray()
            elif b == FRAME_STOP:
                if isinstance(_partial_frame, bytearray):
                    unstuffed_frames.append(_partial_frame)
                _partial_frame = None
            else:
                if isinstance(_partial_frame, bytearray):
                    _partial_frame.append(b)

# AXLE_SENSOR_COUNTER_SAMPLE_RATE ist von der MSP432 clock abhängig. Die ISR lauft auf 1/16 of ACLK (32MHz).
# der counter incrementiert jede 4 ISR cycles
AXLE_SENSOR_COUNTER_SAMPLE_RATE= 2000./ 4
def parse_msg(frame):
    header=frame[0]
    raw_data= frame[1:]
    d={}
    #
    if header==MSG_HEADER_AXLE:
        on,off =struct.unpack('<BI',raw_data) #little endian unsigned Byte unsigned Int
        d['header'] = "MSG_HEADER_AXLE"
        d['time_wheel_on'] = on / AXLE_SENSOR_COUNTER_SAMPLE_RATE
        d['time_wheel_off'] = off / AXLE_SENSOR_COUNTER_SAMPLE_RATE
    elif header==MSG_HEADER_AXLE_ERROR:
        d['header'] = "MSG_HEADER_AXLE_ERROR"
        d['time_wheel_on'] = None
        d['time_wheel_off'] = int.from_bytes(raw_data[0:4],'little') / AXLE_SENSOR_COUNTER_SAMPLE_RATE
    elif header == MSG_HEADER_SETUP_OK:
        d['header'] = "MSG_HEADER_SETUP_OK"
        d['msg_in'] = raw_data[0]
    elif header == MSG_HEADER_SETUP_ERROR:
        d['header'] = "MSG_HEADER_SETUP_ERR"
        d['msg_in'] = raw_data[0]
    elif header == MSG_HEADER_SUM_LEN:
        d['header'] = "MSG_HEADER_SUM_LEN"
        d['sum_len'] = raw_data[0]
    elif header == MSG_HEADER_T_ERR:
        d['header'] = "MSG_HEADER_T_ERR"
        d['thresholdERR'] = raw_data[0]
    elif header == MSG_HEADER_T_OFF:
        d['header'] = "MSG_HEADER_T_OFF"
        d['thresholdOFF'] = raw_data[0]
    elif header == MSG_HEADER_T_ON:
        d['header'] = "MSG_HEADER_T_ON"
        d['thresholdON'] = raw_data[0]
    elif header == MSG_HEADER_ECHO:
        d['header'] = "MSG_HEADER_PING"
        d['echo'] = raw_data[0]-MSG_ECHO
    else:
        raise AxleSensorException("Message header {} is unvalid.".format(header))
    return d
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

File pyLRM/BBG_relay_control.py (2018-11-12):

import Adafruit_BBIO.GPIO as gpio
import time

POWER_GPIO = "P9_29"  # GPIO_121
PIN = POWER_GPIO
# PIN HIGH -> RELAY close
# PIN LOW -> RELAY open

def relay_setup_gpio():
    gpio.setup(PIN,gpio.OUT,gpio.PUD_DOWN)
    #gpio.setup(POWER_GPIO, gpio.OUT, gpio.HIGH, 100)

def relay_turn_on():
    gpio.output(PIN,0)

def relay_turn_off():
    gpio.output(PIN,1)

def relay_cycle_power(logger):
    logger.info("===Power Cycle xl2.")
    logger.debug("setup gpio")
    relay_setup_gpio()
    logger.info("Power OFF.")
    relay_turn_off()
    time.sleep(1)
    logger.info("Power ON.")
    relay_turn_on()

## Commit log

2018-10-17 Added firmware for axle sensor.
2018-10-17 axle sensor stuff working. Rest broken.
    [axle_sensor.py, config.py, logging_handler.py]
2018-10-22 Add arguments to test_axle_sensor.py: - Arguments for setting up axle sensors - Other general Arguments
    Other:
    - Improved logging formatter
2018-11-12 added xl2_device.py script. The script serve as rool for mounting, umounting xl2 devices. added udev rules for xl2_device.py removed unused old files
2018-11-27 documentation und assign_tools
2018-12-01 axle sensor documentation
